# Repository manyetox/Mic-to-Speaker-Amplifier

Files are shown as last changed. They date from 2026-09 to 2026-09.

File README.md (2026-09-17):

# Multi-Microphone Audio Amplifier

**Compact microphone preamplifier and speaker-amplifier PCB supporting analog MEMS and electret microphone options.**

This project combines a microphone front end, an **MCP6281 preamplifier**, adjustable signal level, and an **LM386 speaker amplifier** on a single 50 × 50 mm PCB. It was developed as a reusable audio front end for electronics experiments, communication projects, and compact standalone audio systems.

The repository contains the editable KiCad design and production-ready V1.1 Gerber files. A physical prototype has also been assembled.

<!-- Add your photo as Media/circuit-photo.jpg, then remove this comment marker:
![Assembled microphone amplifier](Media/circuit-photo.jpeg)
-->
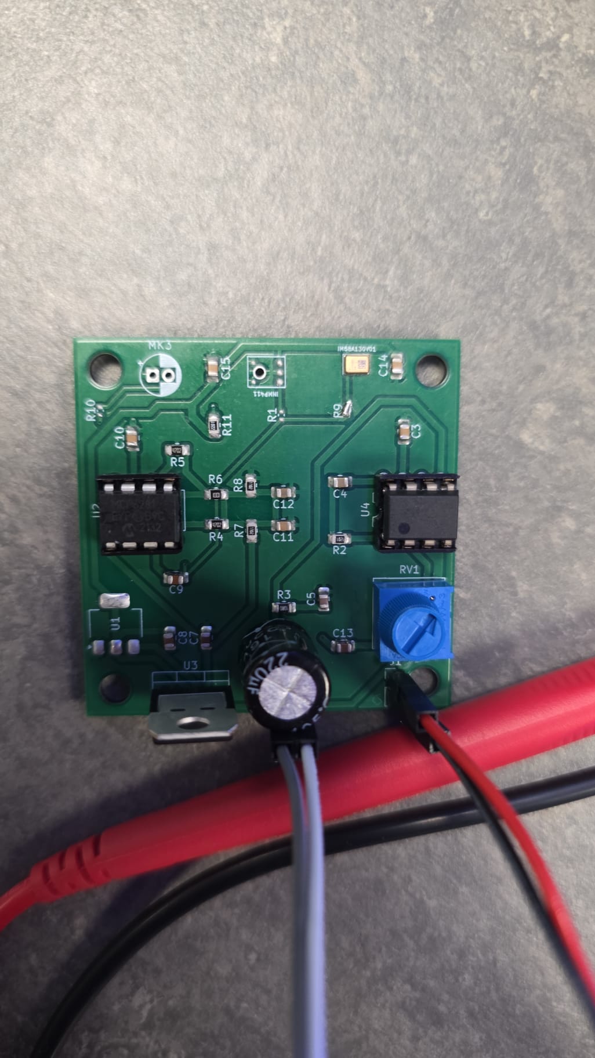
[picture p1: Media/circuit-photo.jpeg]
Assembled microphone amplifier


> **Status:** PCB designed and manufactured; prototype photo available  
> **Input supply:** Regulated 5 V  
> **Audio stages:** MCP6281 preamplifier + LM386 speaker amplifier  
> **Microphone options:** INMP411, IM68A130V01, or KPCM-G60H50P/external electret input  
> **PCB:** Two-layer, 50 × 50 mm, 1.6 mm thick

## Why I Built This

Testing analog microphones often requires several separate modules: a microphone breakout, low-level preamplifier, volume control, speaker amplifier, voltage regulator, and extensive wiring. That arrangement is useful for early breadboard testing, but it becomes bulky and noise-prone in a finished experiment.

This board integrates those functions into one compact platform. It also provides several microphone footprints so different analog microphone technologies can be compared using the same downstream amplification chain.

## Signal Path

```mermaid
flowchart LR
    A["Microphone option"] --> B["Input coupling"]
    B --> C["MCP6281 preamp"]
    C --> D["10 kΩ level control"]
    D --> E["LM386 speaker amp"]
    E --> F["External speaker"]
```

The selected microphone produces the shared `Mic-out` signal. The MCP6281 stage raises the low-level microphone signal, after which the 10 kΩ potentiometer sets the level presented to the LM386. The LM386 then drives an external speaker through the output-coupling network.

## Features

- Three microphone-source options on one PCB
- Low-voltage MCP6281 analog preamplifier
- LM386 power amplifier for a small external speaker
- Adjustable 10 kΩ signal-level control
- Onboard 5 V to 3.3 V regulation for microphone circuitry
- AC-coupled audio stages with local supply decoupling
- LM386 output network with a 250 µF coupling capacitor
- Mostly hand-solderable 0805 passives and DIP amplifier packages
- Two-layer 50 × 50 mm PCB
- Four 4 mm mounting holes
- Editable KiCad 10 source files
- Manufacturing-ready V1.1 Gerber and drill files

## Microphone Options

The PCB includes footprints for multiple analog microphone sources:

| Reference | Device | Type |
|---|---|---|
| `INMP1` | INMP411 | Analog MEMS microphone |
| `IM68A130V1` | IM68A130V01 | Analog MEMS microphone |
| `MK3` / `J1` | KPCM-G60H50P or external microphone | Through-hole/electret option |

The zero-ohm routing links in the design allow the desired source to feed the common microphone-output net. Check the schematic and populate only the intended microphone path before powering the board.

## Main Hardware

| Component | Function |
|---|---|
| MCP6281 | Microphone preamplifier |
| LM386 | Speaker power amplifier |
| 10 kΩ potentiometer | Audio-level adjustment |
| LD1117-3.3 regulators | 3.3 V supply generation |
| 250 µF capacitor | Speaker-output coupling |
| 0805 resistors and capacitors | Biasing, gain setting, filtering, and decoupling |
| 2-pin speaker header | External speaker connection |

## Power

The analog amplifier circuitry is designed around a **regulated 5 V supply**. Onboard LD1117-3.3 regulator stages generate the 3.3 V rails required by the microphone circuitry.

Use a clean, current-limited 5 V source during initial testing. Confirm supply polarity and check the 3.3 V rails before fitting sensitive microphone components.

## PCB

| Property | Value |
|---|---:|
| Dimensions | 50 × 50 mm |
| Copper layers | 2 |
| Thickness | 1.6 mm |
| Copper weight | 35 µm per layer in the stored stack-up |
| Mounting holes | 4 × 4 mm |
| Design tool | KiCad 10 |
| Board revision | V1.1 |

## Connecting and Testing

1. Inspect the assembled board for solder bridges and incorrect component orientation.
2. Select and populate the intended microphone path.
3. Connect a current-limited regulated 5 V supply.
4. Verify the 3.3 V rails before installing or testing the microphone.
5. Connect a suitable small speaker to the speaker-output header.
6. Start with the level potentiometer turned down.
7. Apply an acoustic input and increase the level gradually while checking for clipping, oscillation, or overheating.

The LM386 can draw significant transient current when driving a low-impedance speaker. Keep power leads short and use a supply capable of handling the load without excessive voltage drop.

## Repository Structure

```text
Multi-Microphone-Audio-Amplifier/
├── README.md
├── LICENSE
├── .gitignore
├── GITHUB_SETUP.md
├── Hardware/
│   ├── KiCad/
│   │   ├── Microphone amp.kicad_pro
│   │   ├── Microphone amp.kicad_sch
│   │   └── Microphone amp.kicad_pcb
│   └── Gerbers/
│       ├── GerberV1.1.zip
│       └── manufacturing files
└── Media/
    ├── README.md
    └── circuit-photo.jpg
```

## Manufacturing

The latest manufacturing package is:

[`Hardware/Gerbers/GerberV1.1.zip`](Hardware/Gerbers/GerberV1.1.zip)

Before ordering, inspect the Gerbers in the board manufacturer's viewer and confirm:

- board outline and 50 × 50 mm dimensions
- drill and mounting-hole sizes
- copper, mask, and silkscreen alignment
- selected PCB thickness and copper weight
- component availability and footprints

## Known Limitations

- Only one microphone path should be treated as the active source unless the routing and bias networks are intentionally modified.
- The board does not include automatic gain control.
- The LM386 output is intended for small speakers, not high-power audio loads.
- Analog performance depends strongly on microphone selection, assembly, grounding, speaker impedance, and supply quality.
- This is an experimental electronics project and has not been certified as a commercial audio product.

## Possible Future Improvements

- Measured frequency-response and noise plots
- Oscilloscope captures for each amplifier stage
- Clearly labelled external power connector
- Input-source selection using jumpers or a switch
- Reverse-polarity and over-current protection
- Updated revision with a smaller board outline
- Audio demonstration video

## License

This project is available for personal, educational, academic-research, and other non-commercial use under the terms in [LICENSE](LICENSE). Commercial use requires separate written permission.

## Author

Designed by **Taylan ARSLAN**.

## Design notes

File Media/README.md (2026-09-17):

# Media

Add the assembled-circuit photograph to this directory using the filename:

```text
circuit-photo.jpg
```

Then uncomment the prepared image line near the top of the main `README.md` file.

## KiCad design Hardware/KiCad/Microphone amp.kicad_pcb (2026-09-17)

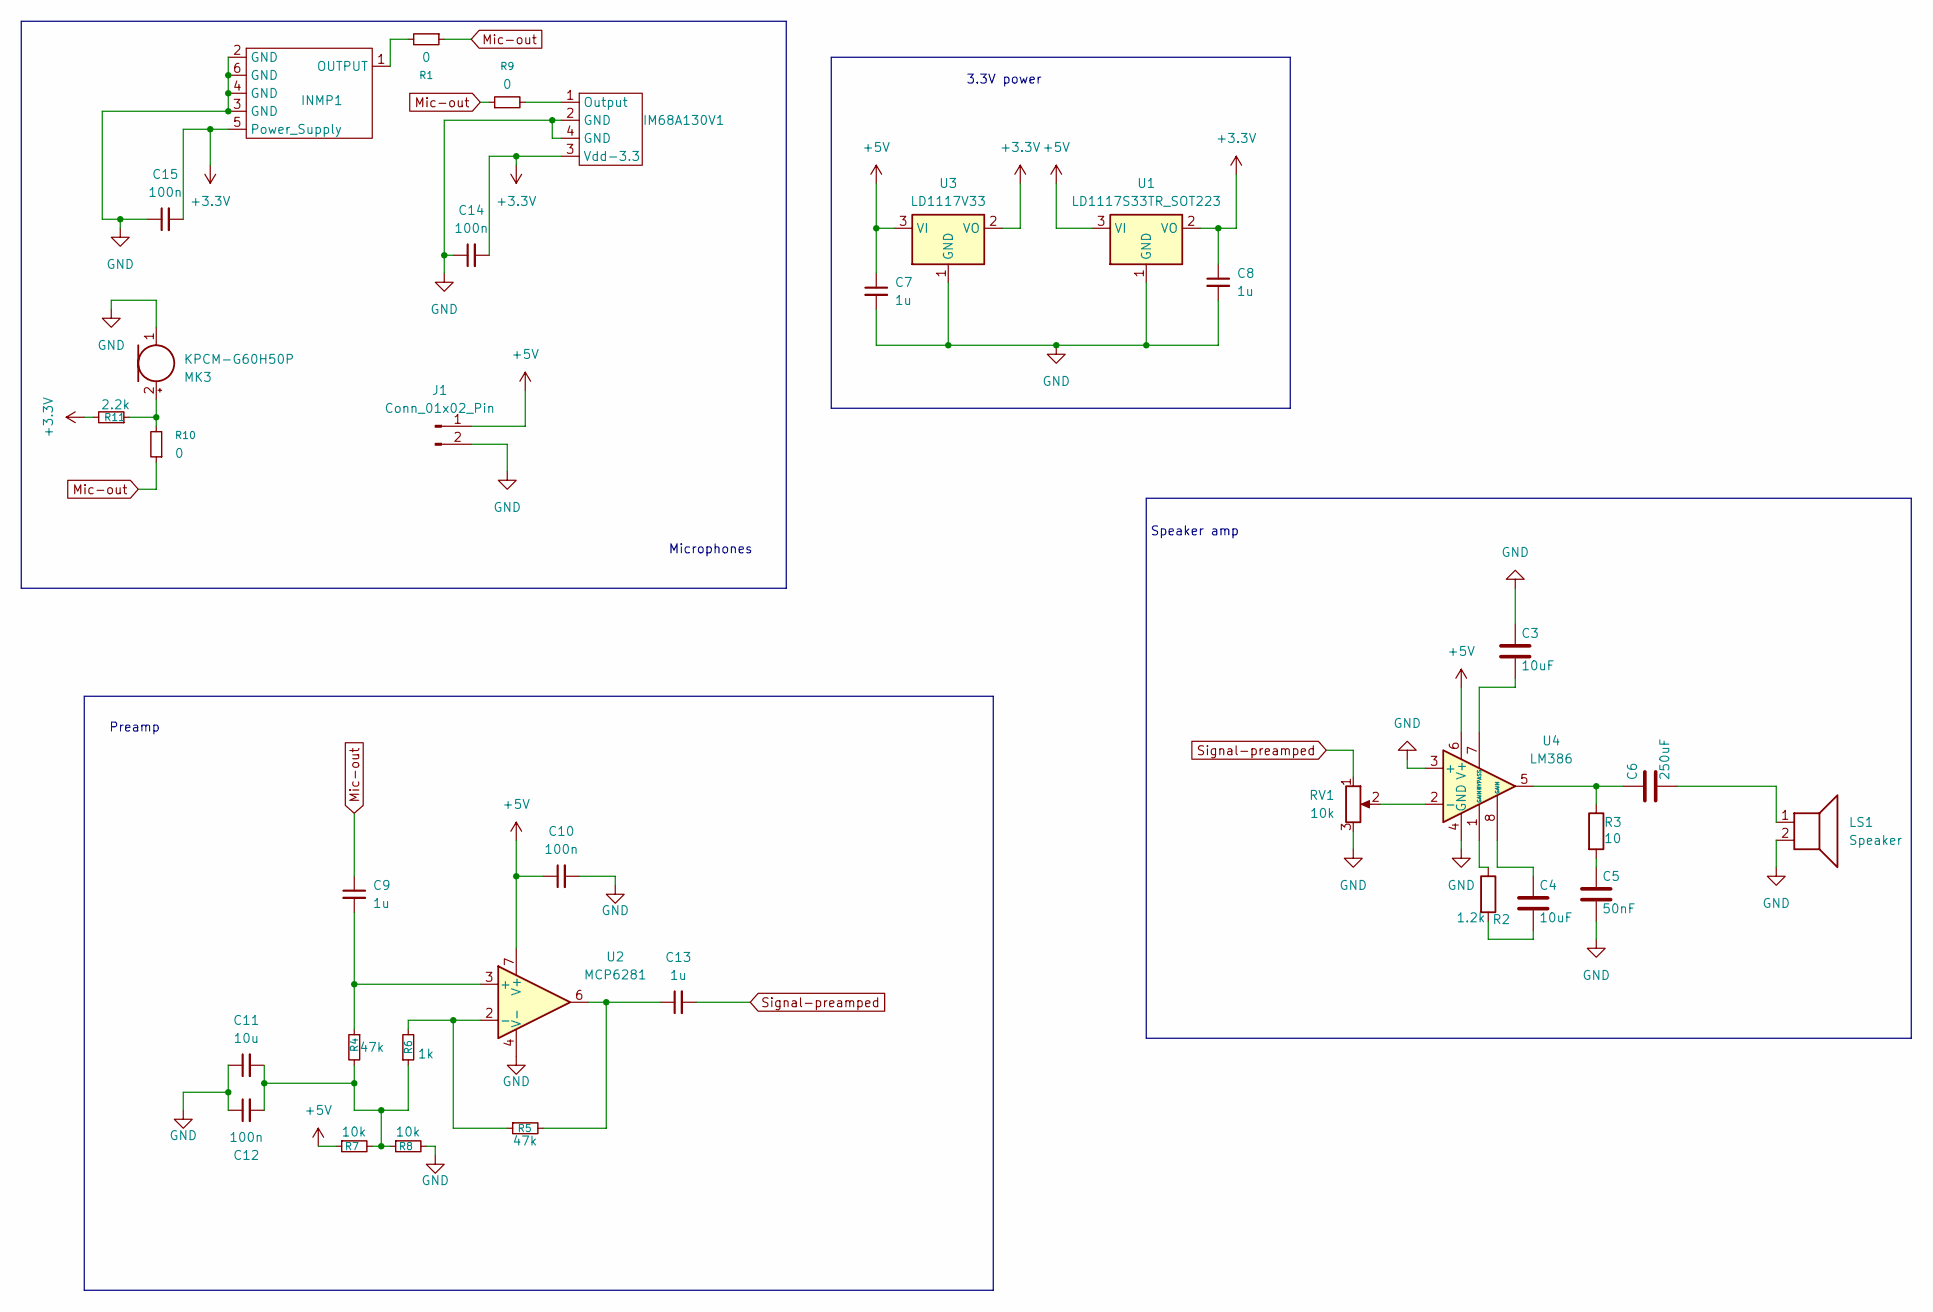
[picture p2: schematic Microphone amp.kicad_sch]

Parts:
C3, C4: 10uF; C_0805_2012Metric_Pad1.18x1.45mm_HandSolder
C5: 50nF; C_0805_2012Metric_Pad1.18x1.45mm_HandSolder
C6: 250uF; C_Radial_D6.3mm_H7.0mm_P2.50mm
C7, C8, C9, C13: 1u; C_0805_2012Metric_Pad1.18x1.45mm_HandSolder
C10, C12, C14, C15: 100n; C_0805_2012Metric_Pad1.18x1.45mm_HandSolder
C11: 10u; C_0805_2012Metric_Pad1.18x1.45mm_HandSolder
IM68A130V1: IM68A130V01
INMP1: INMP411
J1: Conn_01x02_Pin; PinHeader_1x02_P2.54mm_Vertical
LS1: Speaker; PinHeader_1x02_P2.54mm_Vertical
MK3: KPCM-G60H50P; CP_Radial_D5.0mm_P2.00mm
R1, R9, R10: 0; R_0402_1005Metric
R2: 1.2k; R_0805_2012Metric_Pad1.20x1.40mm_HandSolder
R3: 10; R_0805_2012Metric_Pad1.20x1.40mm_HandSolder
R4, R5: 47k; R_0805_2012Metric_Pad1.20x1.40mm_HandSolder
R6: 1k; R_0805_2012Metric_Pad1.20x1.40mm_HandSolder
R7, R8: 10k; R_0805_2012Metric_Pad1.20x1.40mm_HandSolder
R11: 2.2k; R_0805_2012Metric_Pad1.20x1.40mm_HandSolder
RV1: 10k; Potentiometer_Bourns_3386F_Vertical
U1: LD1117S33TR_SOT223; SOT-223-3_TabPin2
U2: MCP6281; DIP-8_W7.62mm
U3: LD1117V33; TO-220-3_Vertical
U4: LM386; DIP-8_W7.62mm_LongPads

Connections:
+3.3V: C8.1, C14.2, C15.2, IM68A130V1.3 (Vdd-3.3), INMP1.5 (Power_Supply), R11.2, U1.2 (VO), U3.2 (VO)
+5V: C7.1, C10.1, J1.1, R7.1, U1.3 (VI), U2.7 (V+), U3.3 (VI), U4.6 (V+)
GND: C3.1, C5.2, C7.2, C8.2, C10.2, C11.1, C12.1, C14.1, C15.1, IM68A130V1.2 (GND), IM68A130V1.4 (GND), INMP1.2 (GND), INMP1.3 (GND), INMP1.4 (GND), INMP1.6 (GND), J1.2, LS1.2, MK3.1 (-), R8.2, RV1.3, U1.1 (GND), U2.4 (V-), U3.1 (GND), U4.3 (+), U4.4 (GND)
Mic-out: C9.1, R1.1, R9.1, R10.1
unnamed: C4.1, U4.8 (GAIN)
unnamed: C4.2, R2.2
unnamed: C5.1, R3.2
unnamed: C6.1, R3.1, U4.5
unnamed: C6.2, LS1.1
unnamed: C11.2, C12.2, R4.2, R6.1, R7.2, R8.1
unnamed: C13.1, R5.2, U2.6
unnamed: IM68A130V1.1 (Output), R9.2
unnamed: INMP1.1 (OUTPUT), R1.2
unnamed: MK3.2 (+), R10.2, R11.1
unnamed: R2.1, U4.1 (GAIN)
unnamed: C9.2, R4.1, U2.3 (+)
unnamed: R5.1, R6.2, U2.2 (-)
unnamed: RV1.2, U4.2 (-)
unnamed: C3.2, U4.7 (BYPASS)
Signal-preamped: C13.2, RV1.1

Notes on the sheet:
Preamp
Microphones
Speaker amp
3.3V power

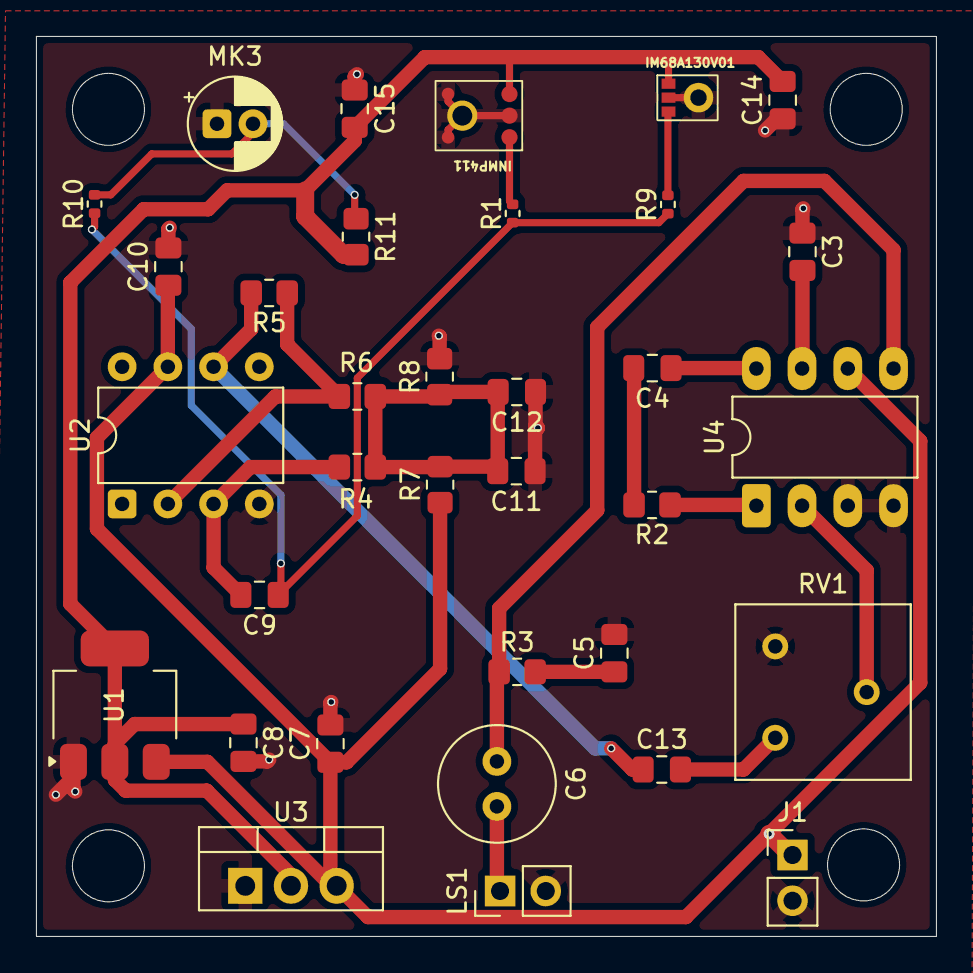
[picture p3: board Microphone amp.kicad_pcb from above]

Board: 2 copper layers, 50.0 x 50.0 mm, 34 parts (0 on the bottom side), 20 nets.

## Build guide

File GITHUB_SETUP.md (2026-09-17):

# GitHub Repository Setup

## Repository name

`Multi-Microphone-Audio-Amplifier`

## Description

`Compact 5 V microphone preamplifier and LM386 speaker-amplifier PCB supporting analog MEMS and electret microphone options, adjustable level control, onboard 3.3 V regulation, and manufacturing-ready KiCad/Gerber files.`

## Suggested topics

`audio-amplifier`, `microphone`, `microphone-preamp`, `mems-microphone`, `electret-microphone`, `lm386`, `mcp6281`, `analog-electronics`, `pcb`, `kicad`, `diy-audio`

## Recommended settings

- Visibility: Public
- Add README during repository creation: Off; this package already includes one
- Add `.gitignore` during repository creation: Off; this package already includes one
- Add license during repository creation: No license; upload the included custom `LICENSE`
- Default branch: `main`

## Add the prototype photo

1. Rename the photograph to `circuit-photo.jpg`.
2. Place it in the `Media` directory.
3. In `README.md`, remove the surrounding HTML comment markers from the prepared image line.
